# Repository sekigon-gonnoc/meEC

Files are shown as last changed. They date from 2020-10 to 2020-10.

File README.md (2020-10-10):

# meEC

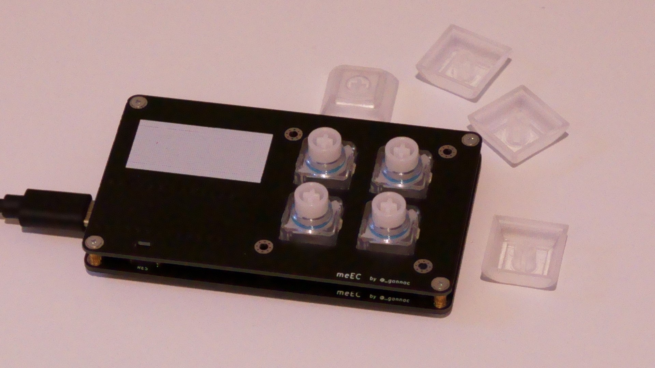
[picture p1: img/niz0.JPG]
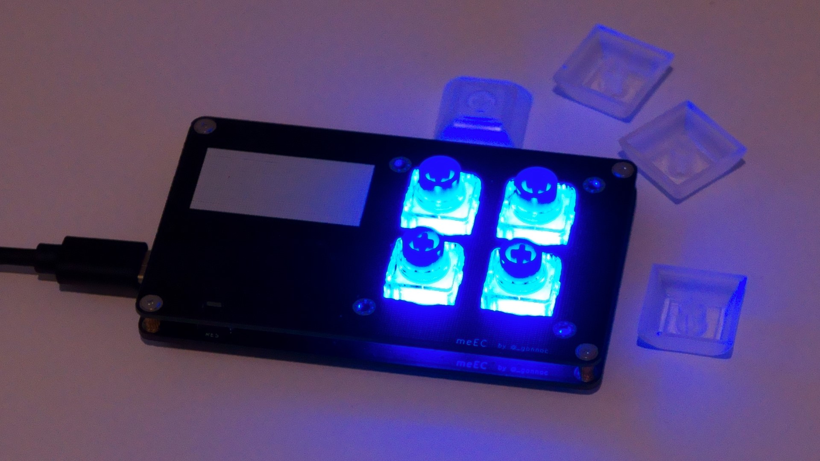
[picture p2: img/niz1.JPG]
| | |
|-|-|
|NIZスイッチLEDなし|NIZスイッチLEDあり|
|||
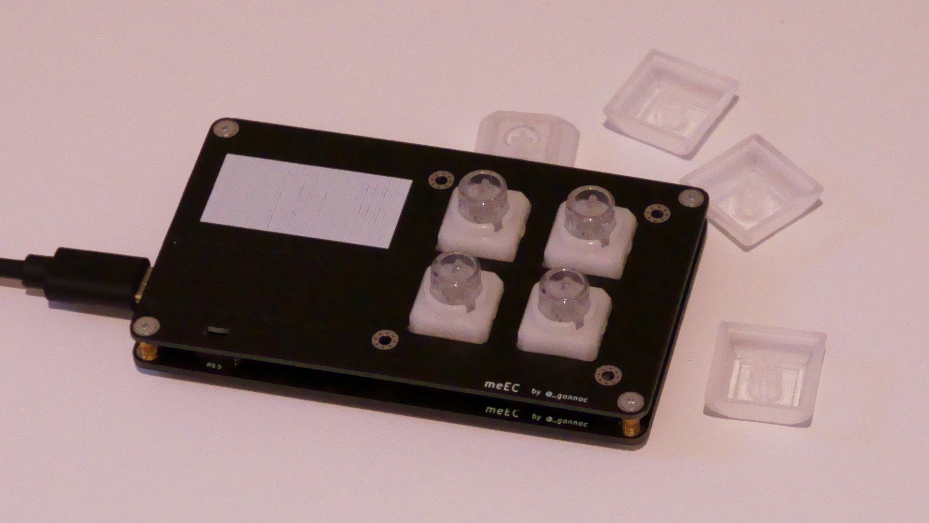
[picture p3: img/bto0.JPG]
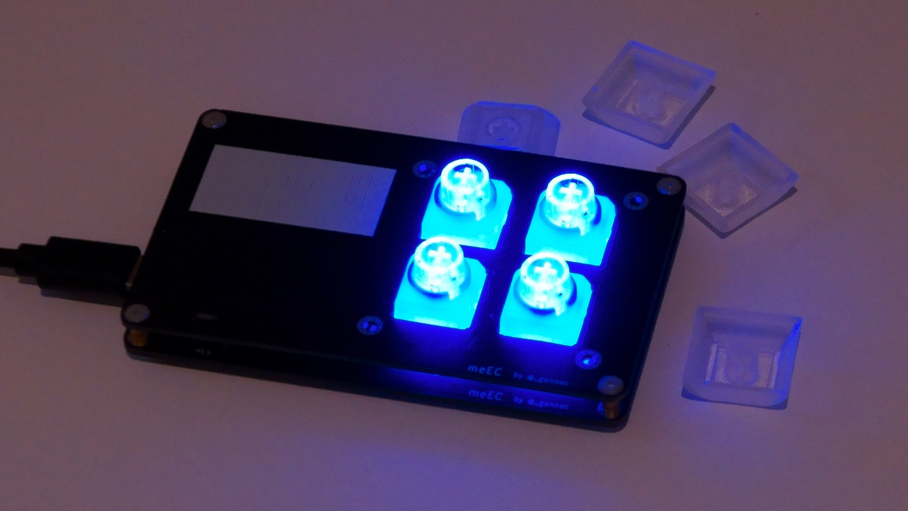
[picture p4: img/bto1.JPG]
| | |
|BTOスイッチLEDなし|BTOスイッチLEDあり|

- [部品リスト](#部品リスト)
  - [キットに同梱されている部品](#キットに同梱されている部品)
  - [キット以外に必要な部品](#キット以外に必要な部品)
- [組み立て手順](#組み立て手順)
  - [EC microにType-Cコネクタをはんだ付けする](#ec-microにtype-cコネクタをはんだ付けする)
  - [(メイン基板にLEDをはんだ付けする)](#メイン基板にledをはんだ付けする)
  - [メイン基板にリセットスイッチをはんだ付けする](#メイン基板にリセットスイッチをはんだ付けする)
  - [メイン基板にEC microを取り付ける](#メイン基板にec-microを取り付ける)
  - [トッププレートにスペーサーをネジ止めする](#トッププレートにスペーサーをネジ止めする)
  - [トッププレートにスイッチを取り付ける](#トッププレートにスイッチを取り付ける)
  - [トッププレートとメイン基板をネジ止めする](#トッププレートとメイン基板をネジ止めする)
- [ファームウェア](#ファームウェア)

## 部品リスト
### キットに同梱されている部品
|部品|数|
|-|-|
|EC micro|1|
|USB Type-C コネクタ|1|
|メイン基板|1|
|トッププレート|1|
|タクトスイッチ|1|
|M2ネジ|8|
|M2x5スペーサー|4|
|ゴム足|4|

### キット以外に必要な部品

|部品|数|入手先|
|-|-|-|
|12ピンコンスルーまたはピンヘッダ|2|遊舎工房など|
||||
|**BTOスイッチ用**|
|ADELCPS 静電容量スイッチ4点セット|4キー分|https://yushakobo.jp/shop/a0500es-01-1/, https://btoshop.jp/2020/09/25/adelcps/mp
|ラバードーム|必要分|https://yushakobo.jp/shop/a0500er-01-1/, https://btoshop.jp/2020/09/25/adelcpru/|
||||
|**NIZ ECスイッチ用**|
|NIZ EC Switch |4|https://www.nizkeyboard.com/collections/ornaments/products/2019-new-niz-ec-switch|
|ラバードーム|必要分|https://www.nizkeyboard.com/collections/ornaments/products/ec-silicone-domes-35g-45g-55g, 上記ラバードームも可|
|コニックリング|4|NIZ用のバラ売りはないのでBTOのセットなどから流用する|
||||
|**LED対応版オプション**|||
|YS-SK6812MINI-E|4|遊舎工房など|

## 組み立て手順
### EC microにType-Cコネクタをはんだ付けする
- 出荷時に貼り付けてあるカプトンテープは剥がさないほうが他の部品とブリッジしづらい
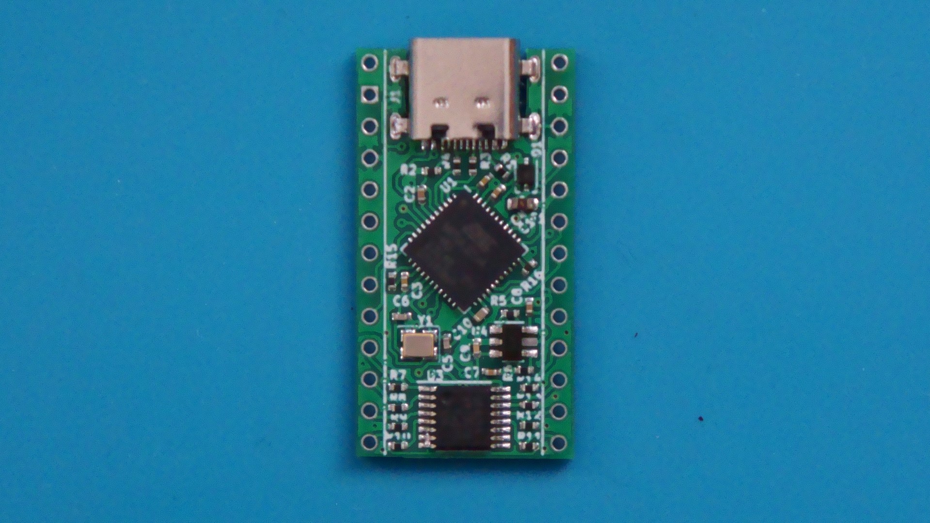
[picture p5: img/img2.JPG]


### (メイン基板にLEDをはんだ付けする)
- 行によってLEDの向きが違うので注意
  - シルクに`/`マークがついている方にLEDの切り欠きを合わせる

### メイン基板にリセットスイッチをはんだ付けする
### メイン基板にEC microを取り付ける
- コンスルーを使う場合、EC micro側もメイン基板側もはんだ付けは不要
- コンスルーはスイッチ側に寄せる
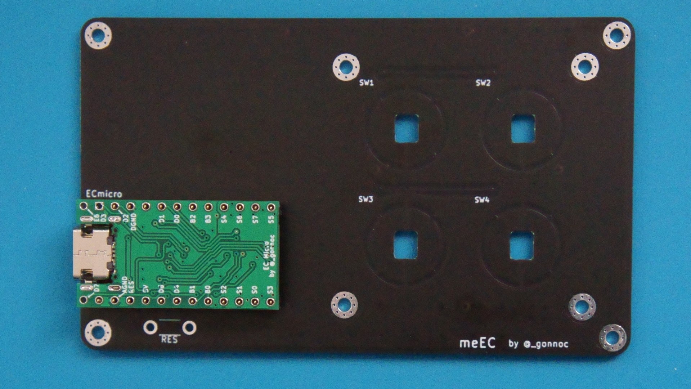
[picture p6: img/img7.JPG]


### トッププレートにスペーサーをネジ止めする
### トッププレートにスイッチを取り付ける
- BTOのスイッチの場合は切り欠きが横向きになるように嵌めて、ラバーシートの切り欠きにスイッチの突起を通す
- ステムの向きに注意
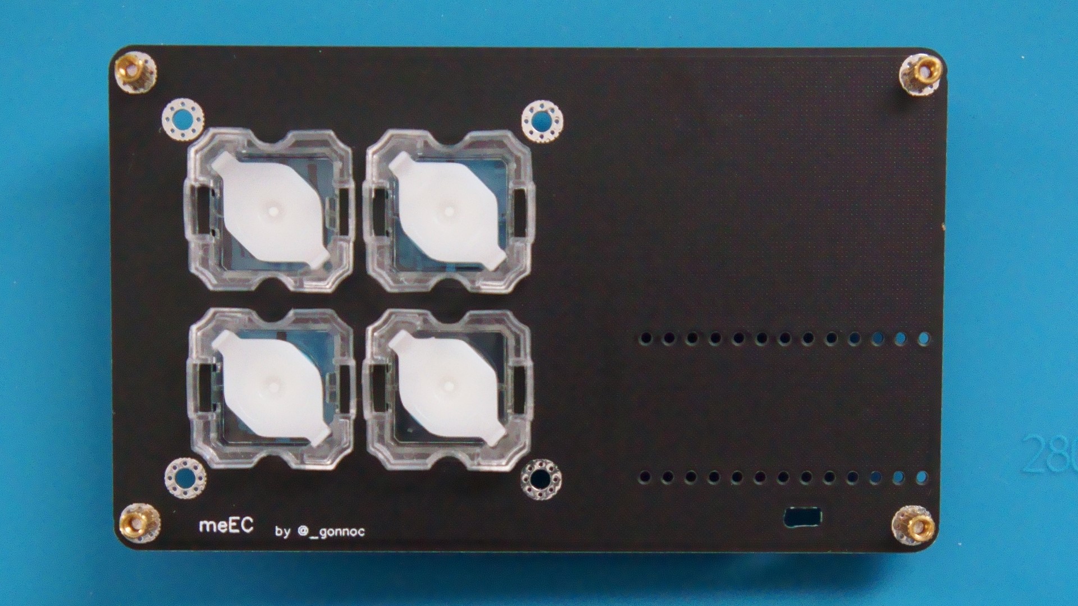
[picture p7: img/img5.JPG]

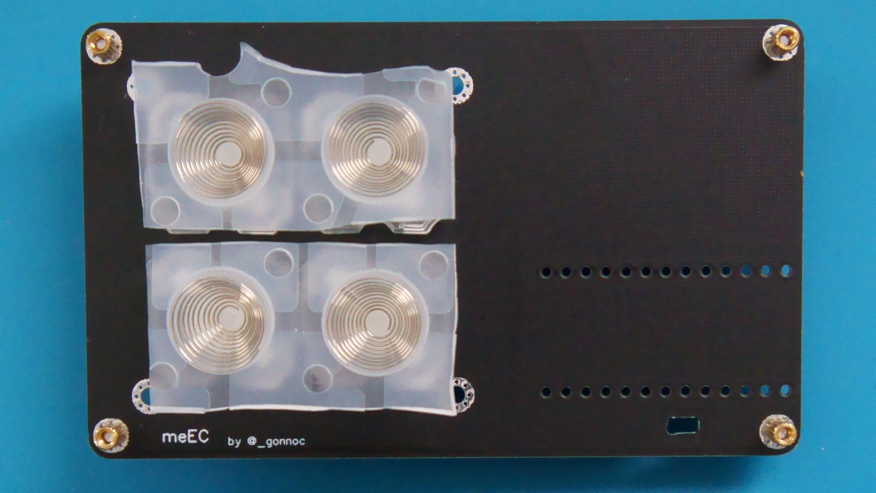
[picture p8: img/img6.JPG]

### トッププレートとメイン基板をネジ止めする
- トッププレートの穴にコンスルーが通っている（コンスルーを押しつぶしていない）ことを確認

## ファームウェア
- リポジトリを取得
  - https://github.com/sekigon-gonnoc/qmk_firmware/tree/dev/sekigon
- atmel-dfu経由で書き込み
  - リセットすると自動でブートローダが起動する
  ```
  make meec:dfu
  ```

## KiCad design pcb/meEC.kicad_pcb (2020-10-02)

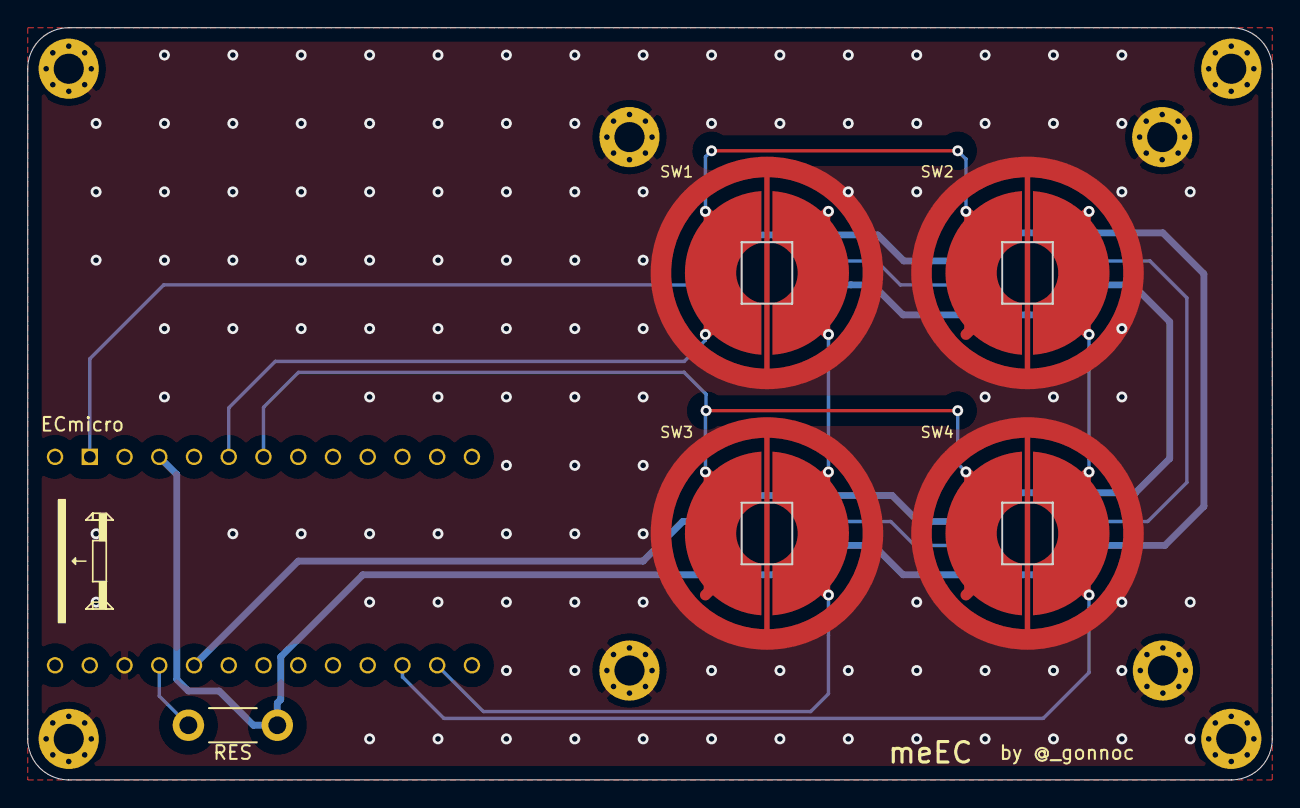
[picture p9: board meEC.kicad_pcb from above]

Board: 2 copper layers, 91.0 x 55.0 mm, 18 parts (1 on the bottom side), 12 nets.

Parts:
D1, D2, D3, D4: WS2812B; YS-SK6812MINI_rev
H1, H2, H3, H4, H5, H6, H7, H8: M2; MountingHole_2.2mm_M2_Pad_Via
SW1, SW2, SW3, SW4: EC_SW; ec_pad_led2
SW5: SW_Push; TactSW_2Pin
U1: ECmicro; BLEMicroPro

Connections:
C0: SW1.2, SW3.2, U1.15
C1: SW2.2, SW4.2, U1.16
GND: D1.3, D2.3, D3.3, D4.3, SW5.2, U1.4
GNDA: H1.1, H2.1, H3.1, H4.1, H5.1, H6.1, H7.1, H8.1, SW1.3, SW2.3, SW3.3, SW4.3, U1.24
LED: D1.4, U1.2
unnamed: D1.2, D2.4
unnamed: D2.2, D3.4
unnamed: D3.2, D4.4
unnamed: SW5.1, U1.23
R0: SW1.1, SW2.1, U1.6
R1: SW3.1, SW4.1, U1.7
VCC: D1.1, D2.1, D3.1, D4.1, U1.22
